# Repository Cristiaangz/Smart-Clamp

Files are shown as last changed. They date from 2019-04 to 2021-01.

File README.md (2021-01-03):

# Smart Clamp Project
This is the GitHub for the Smart Clamp Project under Professor Andras Gyorgy

## 1. Statement of Project Summary
This project aims to develop a low-cost lab equipment add-on that enables remote monitoring of bacterial populations grown in standard lab flasks. The device should be able to accommodate a variety of flasks and bacterial strains, whilst not interfering with the contents’ growth, and utilize IoT capabilities for control and data transmission. Thus, the final prototype will measure cell density, weight, orientation and motion during incubation in temperature controlled shakers, will have inductive wireless charging, WiFi/Bluetooth communication and control capabilities. An onboard microcontroller will be used to direct the device’s functionality. The design layout, material choice, and electronic circuit will be optimized for size, compatibility, power consumption, signal-to-noise ratio, and cost.
## 2. Background and Review of Literature
In the field of microbiology, it is often essential to quantify and monitor cell growth of bacterial populations. Monitoring is done by quantifying cell density over regular time intervals. Quantification is done through either manual counting methods like plating; automated counting methods like flow cytometry; or indirect cell counting like spectrophotometry. All these methodologies have clear drawbacks. Manual and indirect cell counting often requires physical sampling at regular intervals, which requires trained personnel, it is highly time intensive and increases the risk of contamination. Conversely, current automated counting methods require less attention but are either invasive or often prohibitively expensive. Coulter counters require instrumentation to be in contact with the growth medium, making them impractical within an incubator and posing a risk of contamination. Flow cytometry requires highly-specialized and expensive instrumentation, which makes them only accessible to well-funded, high-level research settings where high precision is needed. Thus, a low-cost non-invasive cell-count monitoring system is needed for a large variety of  applications.

This project seeks inspiration from commercially available turbidostats, in their ability to give the user the constant updates on the amount of cells in the apparatus. The instrumentation’s add-on form factor is adopted so that existing experimental protocols require little to no modifications to gain the benefits of the sensory system.  
## 3. Resources 
3D printer, Soldering Tools, Standard Lab Glassware, Basic microbiology equipment. Lab personnel will be available for help. The students and the PI have all the required skillset and tools/equipment for the successful completion of the project.

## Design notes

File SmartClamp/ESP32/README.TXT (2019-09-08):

LAST UPDATED: SEPT 08 2019

This code is meant to work with Esspresif’s ESP32 Dev Board V4 with ESP32-WROOM-32D core. 

PlatformIO is needed to flash the ESP32 with the source code and the required libraries.

PlatformIO is an add-on for Atom or VSCode. It is really helpful as it automatically retrieves and installs libraries for you an allow compile and troubleshoot the same code for different hardware. This can all be defined in the platformio.ini file.

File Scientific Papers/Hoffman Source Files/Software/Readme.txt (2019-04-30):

The turbidostat.ino needs to be flashed onto the Arduino Nano with the Arduino IDE. 
Make sure, the proper driver for the Arduino Nano's chip is installed.

The 'Turbidostat' folder needs to be placed into the current user's home directory. 
(E.g. under Windows typically C:\Users\'UserX')

Start the GUI with the console from the GUI directory with the command 'python turbidostat.py'.

A python distribution containing the used libraries has to be installed.

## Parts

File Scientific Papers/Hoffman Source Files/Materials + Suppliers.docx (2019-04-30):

Part | Supplier URL | Supplier's order number | Price per unit | Amount | total
Electronics, central unit
Photo-coated PCB 200x300 mm | conrad.de | 523695 | 6.86 € | 1 | 6.86 €
MOSFET IRF7103 SO-8 | conrad.de | 162431 | 0.50 € | 2 | 1.00 €
Laser module 1 mW LFD650 | conrad.de | 816476 | 7.50 € | 1 | 7.50 €
bar magnet 5 mm x 20 mm | conrad.de | 505782 | 1.93 € | 2 | 3.86 €
light-to-frequency converter TSL 235 R | conrad.de | 178993 | 3.41 € | 2 | 6.82 €
12V power supply | conrad.de | 512685 | 7.99 € | 1 | 7.99 €
Arduino Nano | reichelt.de | ARDUINO NANO | 24.90 € | 1 | 24.90 €
connector for CPU fan | reichelt.de | PSS 254/3G | 0.05 € | 1 | 0.05 €
female connector, 4 pins | reichelt.de | M 604 | 0.48 € | 2 | 0.96 €
male connector, 4 pins | reichelt.de | B 604 | 0.41 € | 2 | 0.82 €
foil capacitor 4.7 nF | reichelt.de | MKS02-250 4,7N | 0.16 € | 1 | 0.16 €
foil capacitor 100 nF | reichelt.de | MKS-2-5 100N | 0.09 € | 1 | 0.09 €
Hall sensor | reichelt.de | TLE 4905L | 0.67 € | 1 | 0.67 €
12V barrel connector | reichelt.de | HEBW 25 | 0.30 € | 1 | 0.30 €
Female pin header | reichelt.de | BL 1X20G 2,54 | 0.72 € | 2 | 1.44 €
CPU fan 80 mm as stirrer motor | reichelt.de | LÜFTER-8025 12V | 1.45 € | 1 | 1.45 €
long M3 screws, flat-head 50 mm | various suppliers | | 0.30 € | 4 | 1.20 €
sheet metal screws 7 mm | various suppliers | | 0.10 € | 7 | 0.70 €
microscope cover slip as beam splitter | various suppliers | | 0.10 € | 1 | 0.10 €
Tubing system, culture vessel
2x GL 45 lid with tube connectors | carlroth.com | PY86.1 | 50.58 € | 1 | 50.58 €
Luer-tubing connector male | carlroth.com | CT61.1 | 14.16 € | 0.3 | 4.25 €
Luer-tubing connector female | carlroth.com | CT62.1 | 14.16 € | 0.2 | 2.83 €
magnetic stirrer bar, Ø 6 mm x 15 mm | carlroth.com | AKP5.1 | 2.26 € | 1 | 2.26 €
injection cannulas, Ø 2 mm x 100 mm | de.vwr.com | 612-0359 | 50.10 € | 0.25 | 12.53 €
sterile filter 0.2 µm | de.vwr.com | 514-0061 | 33.00 € | 0.02 | 0.66 €
flat bottom test tube 100x25 mm | laborglasshop.de | 100103 | 12.95 € | 0.03 | 0.39 €
pump tubing | gemke-schlauchpumpen.com | Santoprene 4.8x8.0 mm | 10.35 € | 1 | 10.35 €
silicone tubing, inner Ø 5 mm, outer Ø 8 mm | various suppliers | | | | 5.00 €
silicone tubing, inner Ø 1 mm, outer Ø 3 mm | various suppliers | | | | 5.00 €
2 component casting silicone | various suppliers | | | | 2.00 €
Pump unit
12V air pump | pollin.de | 330 036 | 2.50 € | 1 | 2.50 €
peristaltic medium pump | gemke-schlauchpumpen.com | CP82 24V 30 UPM | 45.00 € | 1 | 45.00 €
pump housing | conrad.de | 526033 | 8.08 € | 1 | 8.08 €
total | | | | | 218.29 €

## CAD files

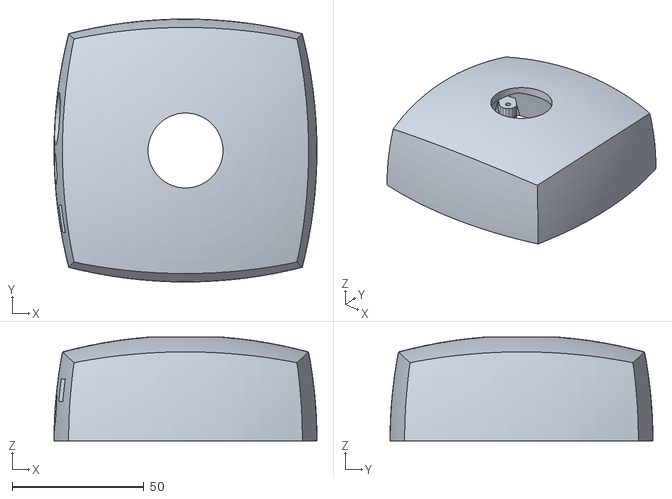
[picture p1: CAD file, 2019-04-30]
Scientific Papers/Hoffman Source Files/journal/upper housing.stl
100.0 x 100.0 x 39.4

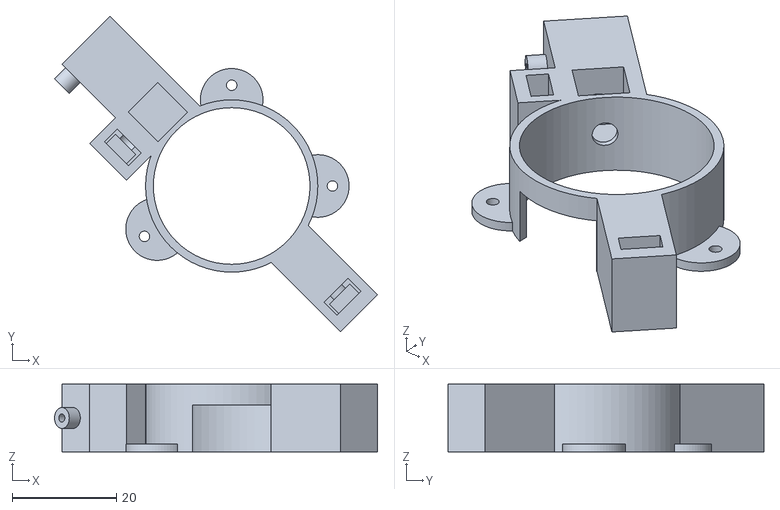
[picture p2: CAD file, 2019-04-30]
Scientific Papers/Hoffman Source Files/journal/optics holder.stl
61.9 x 60.5 x 13.0

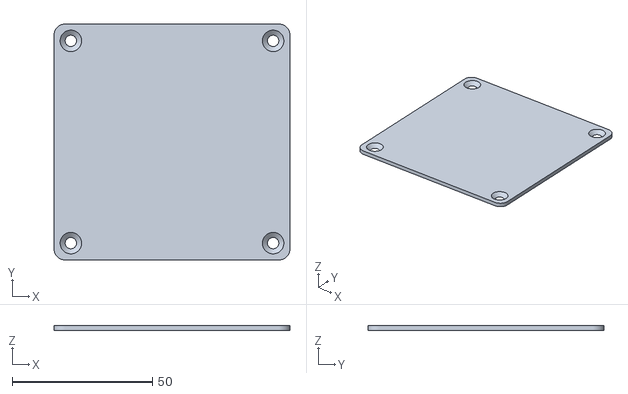
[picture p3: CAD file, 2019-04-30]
Scientific Papers/Hoffman Source Files/journal/bottom cover.stl
84.0 x 84.0 x 1.80

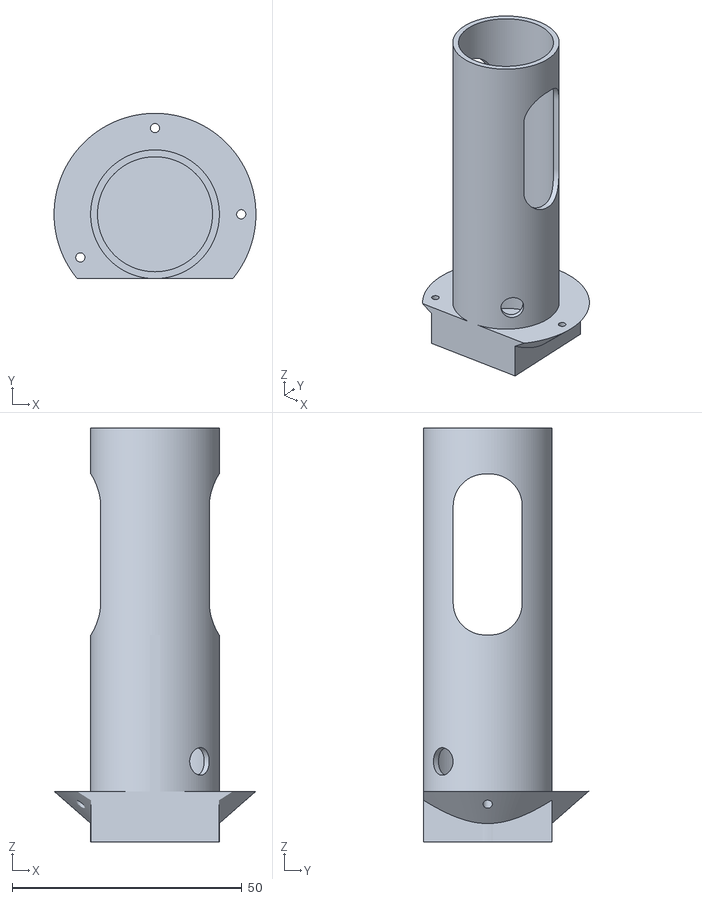
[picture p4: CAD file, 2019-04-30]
Scientific Papers/Hoffman Source Files/journal/tube holder.stl
43.9 x 36.0 x 90.0

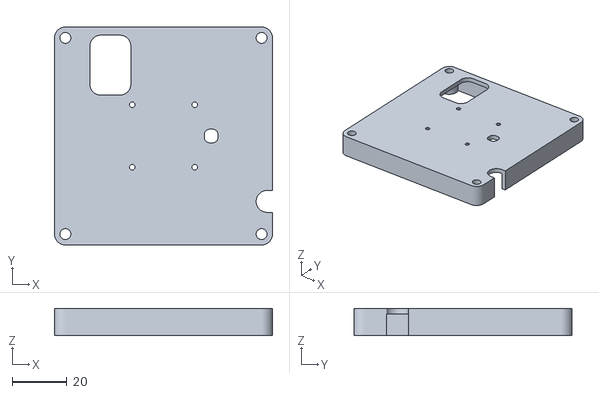
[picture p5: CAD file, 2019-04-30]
Scientific Papers/Hoffman Source Files/journal/base plate.stl
80.0 x 80.0 x 10.0

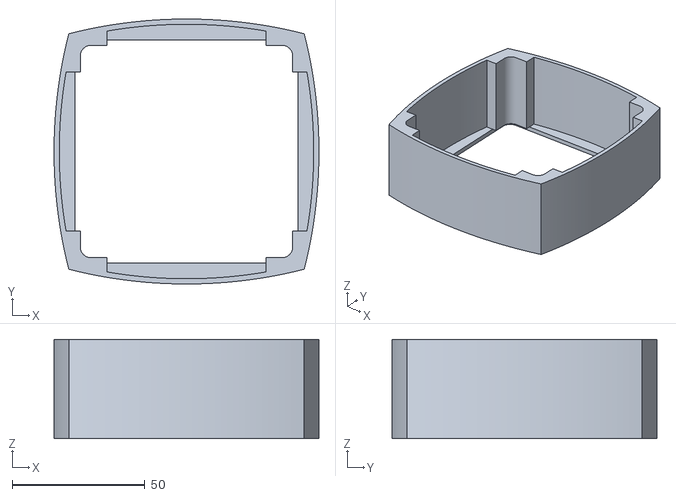
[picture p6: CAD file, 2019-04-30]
Scientific Papers/Hoffman Source Files/journal/lower housing.stl
100.0 x 100.0 x 37.5

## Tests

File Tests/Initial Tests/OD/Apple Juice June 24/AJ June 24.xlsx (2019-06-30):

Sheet: All
Time [s] | 0%1 | 0%2 | 10%1 | 10%2 | 20%1 | 20%2 | 30%1 | 30%2 | 40%1 | 40%2 | 50%1 | 50%2 | 60%1 | 60%2
0 | 0 | 0 | 0 | 0 | 0 | 0 | 0 | 0 | 0 | 0 | 0 | 0 | 0 | 0
1 | 0 | 0 | 0 | 0 | 0 | 0 | 0 | 0 | 0 | 0 | 0 | 0 | 0 | 0
2 | 0 | 0 | 0 | 0 | 0 | 0 | 0 | 0 | 0 | 0 | 0 | 0 | 0 | 0
3 | 0 | 0 | 0 | 0 | 0 | 0 | 0 | 0 | 0 | 0 | 0 | 0 | 0 | 0
4 | 0 | 0 | 0 | 0 | 0 | 0 | 0 | 0 | 0 | 0 | 0 | 0 | 0 | 0
5 | 0 | 0 | 0 | 0 | 0 | 0 | 0 | 0 | 0 | 0 | 0 | 0 | 0 | 0
6 | 0 | 0 | 0 | 0 | 0 | 0 | 0 | 0 | 0 | 0 | 0 | 0 | 0 | 0
7 | 0 | 0 | 0 | 0 | 0 | 0 | 0 | 0 | 0 | 0 | 0 | 0 | 0 | 0
8 | 0 | 0 | 0 | 0 | 0 | 0 | 0 | 0 | 0 | 0 | 0 | 0 | 0 | 0
9 | 0 | 0 | 0 | 0 | 0 | 0 | 0 | 0 | 0 | 0 | 0 | 0 | 0 | 0
10 | 0 | 0 | 0 | 0 | 0 | 0 | 0 | 0 | 0 | 0 | 0 | 0 | 0 | 0
11 | 0 | 0 | 0 | 0 | 0 | 0 | 0 | 0 | 0 | 0 | 0 | 0 | 0 | 0
12 | 0 | 0 | 0 | 0 | 0 | 0 | 0 | 0 | 0 | 0 | 0 | 0 | 0 | 0
13 | 0 | 0 | 0 | 0 | 0 | 0 | 0 | 0 | 0 | 0 | 0 | 0 | 0 | 0
14 | 0 | 0 | 0 | 0 | 0 | 0 | 0 | 0 | 0 | 0 | 0 | 0 | 0 | 0
15 | 0 | 0 | 0 | 0 | 0 | 0 | 0 | 0 | 0 | 0 | 0 | 0 | 0 | 0
16 | 0 | 0 | 0 | 0 | 0 | 0 | 0 | 0 | 0 | 0 | 0 | 0 | 0 | 0
17 | 0 | 0 | 0 | 0 | 0 | 0 | 0 | 0 | 0 | 0 | 0 | 0 | 0 | 0
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

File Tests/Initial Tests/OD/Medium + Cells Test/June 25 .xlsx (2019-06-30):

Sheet: Raw Data
Time [s] | Sat1 | Sat2 | Sat3 | 1/2 1 | 1/2 2 | 1/2 3 | 1/4 1 | 1/4 2 | 1/4 3 | 1/8 1 | 1/8 2 | 1/8 3 | 1/16 1 | 1/16 2 | 1/16 3 | 1/32 1 | 1/32 2 | 1/32 3 | 1/64 1 | 1/64 2 | 1/64 3 | 1/128 1 | 1/128 2 | 1/128 3 | LB1 | LB2 | LB3
0 | 0 | 0 | 0 | 0 | 0 | 0 | 0 | 0 | 0 | 0 | 0 | 0 | 0 | 0 | 0 | 0 | 0 | 0 | 0 | 0 | 0 | 0 | 0 | 0 | 0 | 0 | 0
1 | 0 | 0 | 0 | 0 | 0 | 0 | 0 | 0 | 0 | 0 | 0 | 0 | 0 | 0 | 0 | 0 | 0 | 0 | 0 | 0 | 0 | 0 | 0 | 0 | 0 | 0 | 0
2 | 0 | 0 | 0 | 0 | 0 | 0 | 0 | 0 | 0 | 0 | 0 | 0 | 0 | 0 | 0 | 0 | 0 | 0 | 0 | 0 | 0 | 0 | 0 | 0 | 0 | 0 | 0
3 | 0 | 0 | 0 | 0 | 0 | 0 | 0 | 0 | 0 | 0 | 0 | 0 | 0 | 0 | 0 | 0 | 0 | 0 | 0 | 0 | 0 | 0 | 0 | 0 | 0 | 0 | 0
4 | 0 | 0 | 0 | 0 | 0 | 0 | 0 | 0 | 0 | 0 | 0 | 0 | 0 | 0 | 0 | 0 | 0 | 0 | 0 | 0 | 0 | 0 | 0 | 0 | 0 | 0 | 0
5 | 0 | 0 | 0 | 0 | 0 | 0 | 0 | 0 | 0 | 0 | 0 | 0 | 0 | 0 | 0 | 0 | 0 | 0 | 0 | 0 | 0 | 0 | 0 | 0 | 0 | 0 | 0
6 | 0 | 0 | 0 | 0 | 0 | 0 | 0 | 0 | 0 | 0 | 0 | 0 | 0 | 0 | 0 | 0 | 0 | 0 | 0 | 0 | 0 | 0 | 0 | 0 | 0 | 0 | 0
7 | 0 | 0 | 0 | 0 | 0 | 0 | 0 | 0 | 0 | 0 | 0 | 0 | 0 | 0 | 0 | 0 | 0 | 0 | 0 | 0 | 0 | 0 | 0 | 0 | 0 | 0 | 0
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

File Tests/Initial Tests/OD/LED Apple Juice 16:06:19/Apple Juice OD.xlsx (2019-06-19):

Time | 100% Uncap | 90% Uncap | 80% Uncap | 70% Uncap | 60% Uncap | 50% Uncap | 40% Uncap | 30% Uncap | 20% Uncap | 10% Uncap | 0% Uncap | No Flask
1 | 2626 | 2636 | 2736 | 2773 | 2927 | 3773 | 4422 | 4881 | 5578 | 5836 | 8417 | 2473
2 | 61424 | 64431 | 59963 | 58893 | 60240 | 60019 | 65337 | 63732 | 65390 | 64059 | 68981 | 70966
3 | 61529 | 64438 | 59955 | 58682 | 60228 | 59970 | 65142 | 63764 | 65534 | 64083 | 68697 | 71170
4 | 61650 | 64211 | 59984 | 58808 | 60212 | 59888 | 64940 | 63856 | 65420 | 64056 | 68624 | 71158
5 | 61585 | 64356 | 59935 | 58985 | 60298 | 59989 | 64683 | 63927 | 65607 | 64132 | 68583 | 71144
6 | 61422 | 64334 | 59911 | 59005 | 60046 | 59980 | 64574 | 64091 | 65473 | 64171 | 68606 | 71132
7 | 61410 | 64251 | 59942 | 59001 | 59920 | 60004 | 64439 | 64278 | 65083 | 64203 | 68643 | 71116
8 | 61451 | 64153 | 59873 | 58997 | 60010 | 59999 | 64350 | 64304 | 64596 | 64183 | 68672 | 66573
9 | 61510 | 64058 | 59847 | 56631 | 59809 | 59956 | 64249 | 64330 | 65384 | 64213 | 68611 | 71120
10 | 61531 | 64007 | 59860 | 58996 | 59605 | 59956 | 64062 | 64218 | 65674 | 64303 | 68622 | 71119
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

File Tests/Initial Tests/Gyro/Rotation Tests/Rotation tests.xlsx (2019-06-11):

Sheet: Static 10 Hz
Time [s] | AcX | AcY | AcZ | Gtemp | GyX | GyY | GyZ
0.1 | -404 | -240 | -16708 | 22.93 | -517 | -212 | 12 | RPM | 0
0.2 | -368 | -192 | -16600 | 22.93 | -495 | -241 | 11
0.3 | -388 | -180 | -16724 | 22.88 | -485 | -239 | 23
0.4 | -364 | -216 | -16772 | 22.98 | -481 | -215 | 13
0.5 | -368 | -84 | -16584 | 22.93 | -518 | -238 | 10
0.6 | -440 | -132 | -16584 | 22.93 | -473 | -239 | 9
0.7 | -332 | -156 | -16692 | 22.84 | -485 | -201 | 14
0.8 | -376 | -196 | -16576 | 22.98 | -481 | -238 | 4
0.9 | -348 | -112 | -16664 | 22.88 | -503 | -194 | 14
1 | -360 | -128 | -16696 | 22.88 | -486 | -233 | 18
1.1 | -328 | -184 | -16676 | 22.98 | -479 | -228 | 8
1.2 | -368 | -100 | -16620 | 22.88 | -521 | -206 | 8
1.3 | -344 | -200 | -16676 | 22.84 | -476 | -235 | 1
1.4 | -404 | -204 | -16740 | 22.93 | -486 | -228 | 32
1.5 | -356 | -160 | -16632 | 22.84 | -501 | -216 | 12
1.6 | -268 | -176 | -16652 | 22.98 | -490 | -216 | -1
1.7 | -432 | -216 | -16860 | 22.84 | -487 | -219 | 11
1.8 | -492 | -220 | -16744 | 22.93 | -508 | -219 | 15
1.9 | -312 | -140 | -16528 | 22.84 | -483 | -225 | 10
2 | -336 | -180 | -16620 | 22.98 | -477 | -202 | 2
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

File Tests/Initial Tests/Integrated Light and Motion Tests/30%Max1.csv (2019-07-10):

Time [s] | Intensity A | Laser On | AcX | AcY | AcZ | GyX | GyY | GyZ | MPU Temp [C]
0.0 | 16.666666666666700 | TRUE | 0 | 0 | 0 | 0 | 0 | 0 | 25.4
0.10 | 550.0 | TRUE | 0 | 0 | 0 | 0 | 0 | 0 | 25.4
0.20 | 2150.0 | TRUE | 0 | 0 | 0 | 0 | 0 | 0 | 25.4
0.30 | 2150.0 | TRUE | 0 | 0 | 0 | 0 | 0 | 0 | 25.4
0.40 | 2166.6666666666700 | TRUE | 0 | 0 | 0 | 0 | 0 | 0 | 25.4
0.50 | 2166.6666666666700 | TRUE | 0 | 0 | 0 | 0 | 0 | 0 | 25.4
0.60 | 2150.0 | TRUE | 0 | 0 | 0 | 0 | 0 | 0 | 25.4
0.70 | 2166.6666666666700 | TRUE | 0 | 0 | 0 | 0 | 0 | 0 | 25.4
0.80 | 2150.0 | TRUE | 0 | 0 | 0 | 0 | 0 | 0 | 25.4
0.90 | 2166.6666666666700 | TRUE | 0 | 0 | 0 | 0 | 0 | 0 | 25.4
0.100 | 2166.6666666666700 | TRUE | 0 | 0 | 0 | 0 | 0 | 0 | 25.4
0.110 | 2166.6666666666700 | TRUE | 0 | 0 | 0 | 0 | 0 | 0 | 25.4
0.120 | 2150.0 | TRUE | 0 | 0 | 0 | 0 | 0 | 0 | 25.4
0.130 | 2166.6666666666700 | TRUE | 0 | 0 | 0 | 0 | 0 | 0 | 25.4
0.140 | 2166.6666666666700 | TRUE | 0 | 0 | 0 | 0 | 0 | 0 | 25.4
0.150 | 2150.0 | TRUE | 0 | 0 | 0 | 0 | 0 | 0 | 25.4
0.160 | 2166.6666666666700 | TRUE | 0 | 0 | 0 | 0 | 0 | 0 | 25.4
0.170 | 2166.6666666666700 | TRUE | 0 | 0 | 0 | 0 | 0 | 0 | 25.4
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

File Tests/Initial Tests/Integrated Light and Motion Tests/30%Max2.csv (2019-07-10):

Time [s] | Intensity A | Laser On | AcX | AcY | AcZ | GyX | GyY | GyZ | MPU Temp [C]
0.0 | 16.666666666666700 | TRUE | 0 | 0 | 0 | 0 | 0 | 0 | 25.49411764705880
0.10 | 633.3333333333330 | TRUE | 0 | 0 | 0 | 0 | 0 | 0 | 25.49411764705880
0.20 | 2183.3333333333300 | TRUE | 0 | 0 | 0 | 0 | 0 | 0 | 25.49411764705880
0.30 | 2200.0 | TRUE | 0 | 0 | 0 | 0 | 0 | 0 | 25.49411764705880
0.40 | 2166.6666666666700 | TRUE | 0 | 0 | 0 | 0 | 0 | 0 | 25.49411764705880
0.50 | 2183.3333333333300 | TRUE | 0 | 0 | 0 | 0 | 0 | 0 | 25.49411764705880
0.60 | 2200.0 | TRUE | 0 | 0 | 0 | 0 | 0 | 0 | 25.49411764705880
0.70 | 2183.3333333333300 | TRUE | 0 | 0 | 0 | 0 | 0 | 0 | 25.49411764705880
0.80 | 2166.6666666666700 | TRUE | 0 | 0 | 0 | 0 | 0 | 0 | 25.49411764705880
0.90 | 2183.3333333333300 | TRUE | 0 | 0 | 0 | 0 | 0 | 0 | 25.49411764705880
0.100 | 2183.3333333333300 | TRUE | 0 | 0 | 0 | 0 | 0 | 0 | 25.49411764705880
0.110 | 2183.3333333333300 | TRUE | 0 | 0 | 0 | 0 | 0 | 0 | 25.49411764705880
0.120 | 2183.3333333333300 | TRUE | 0 | 0 | 0 | 0 | 0 | 0 | 25.49411764705880
0.130 | 2183.3333333333300 | TRUE | 0 | 0 | 0 | 0 | 0 | 0 | 25.49411764705880
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

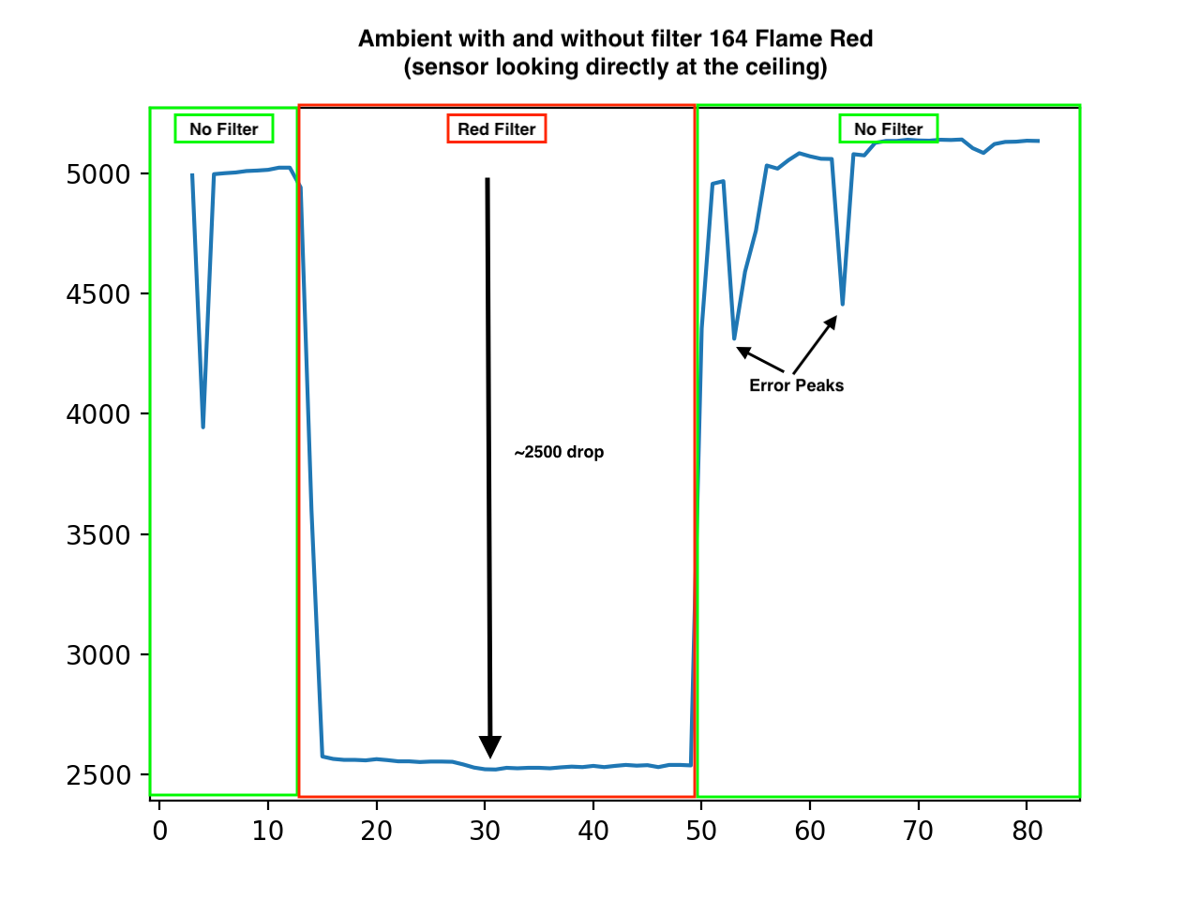
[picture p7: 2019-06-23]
Tests/Initial Tests/OD/Light Detection June 23 2019/Filtered ambient light.png

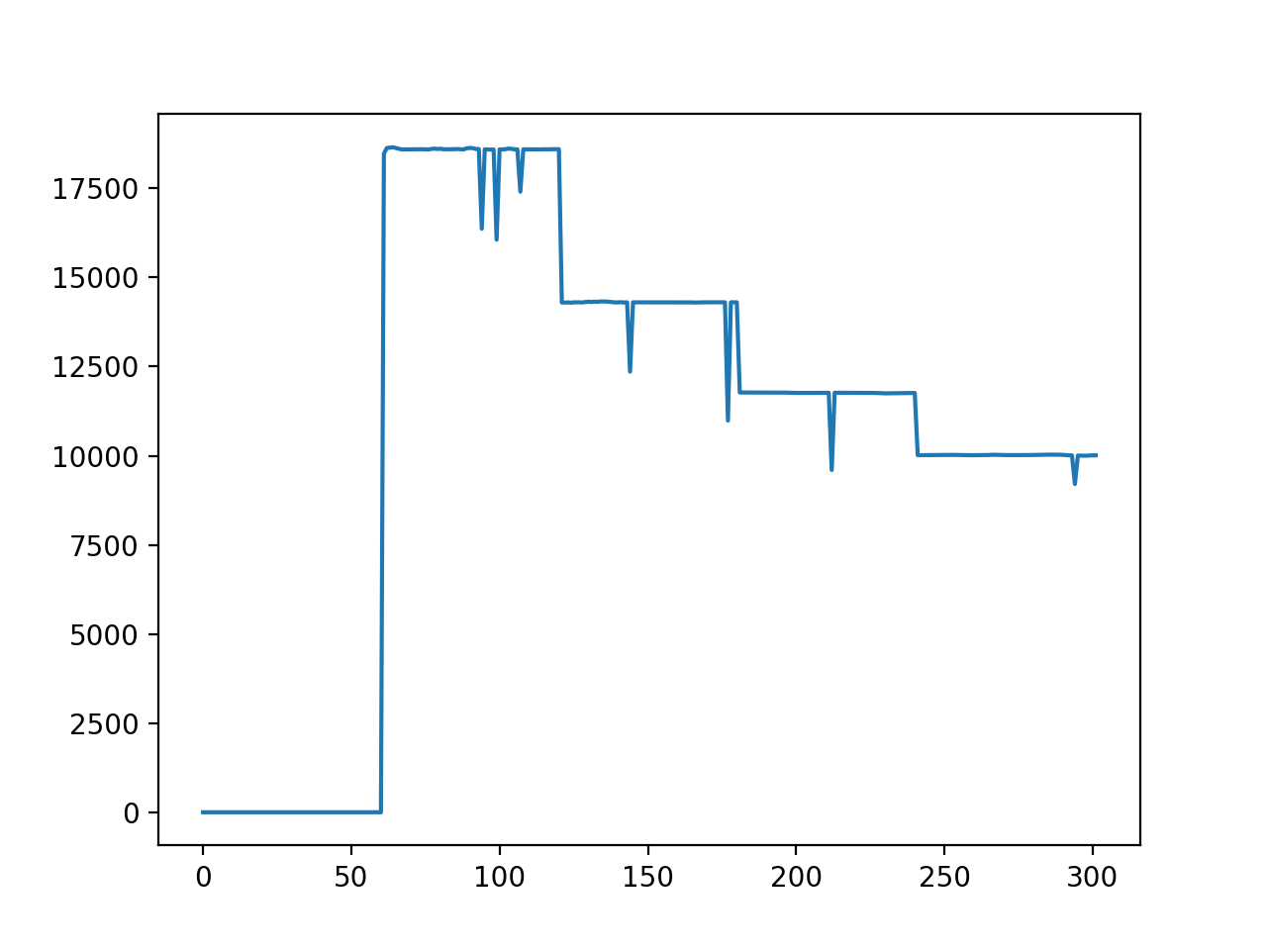
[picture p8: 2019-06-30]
Tests/Initial Tests/OD/Apple Juice June 24/40%AJ2.png

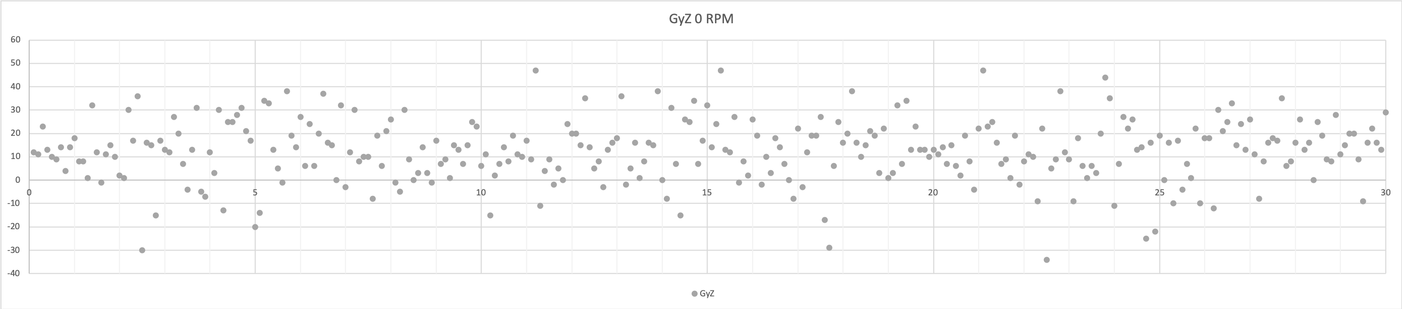
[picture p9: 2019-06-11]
Tests/Initial Tests/Gyro/Rotation Tests/10Hz/Graphs/Static.png/Static.png-6.png

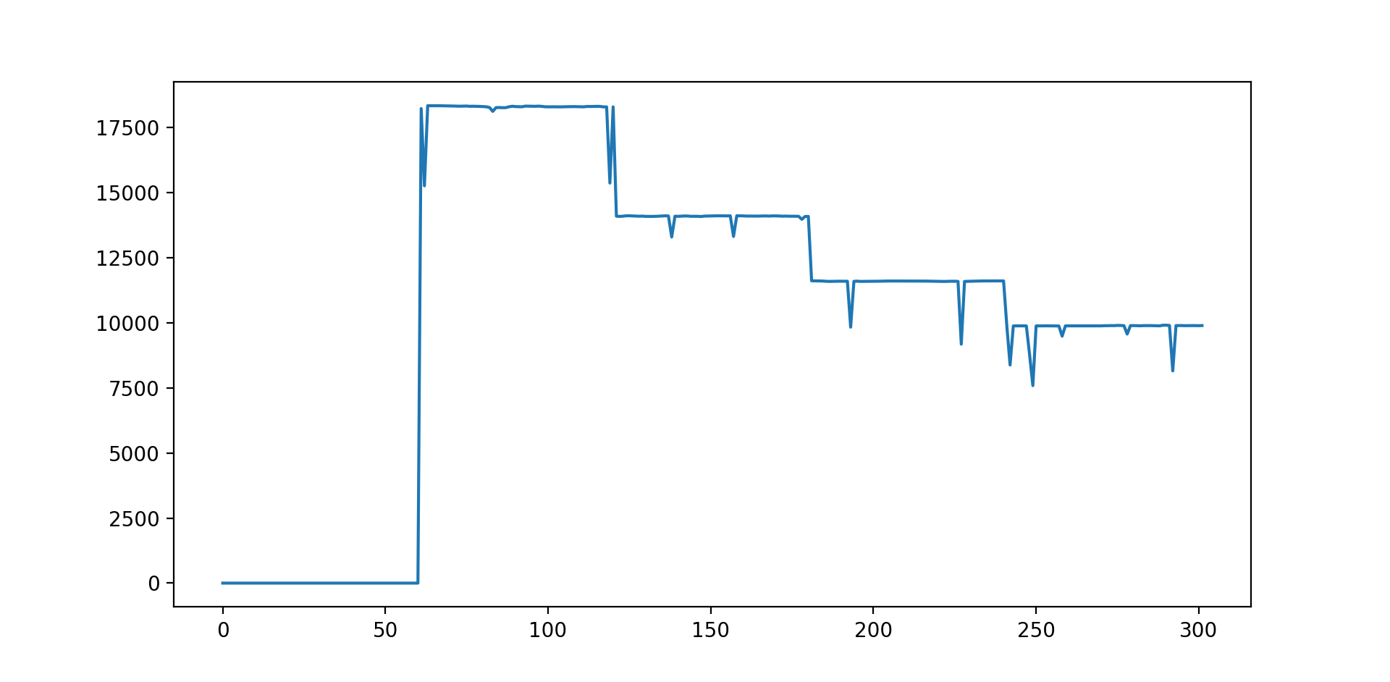
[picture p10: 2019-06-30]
Tests/Initial Tests/OD/Apple Juice June 24/60%AJ1.png

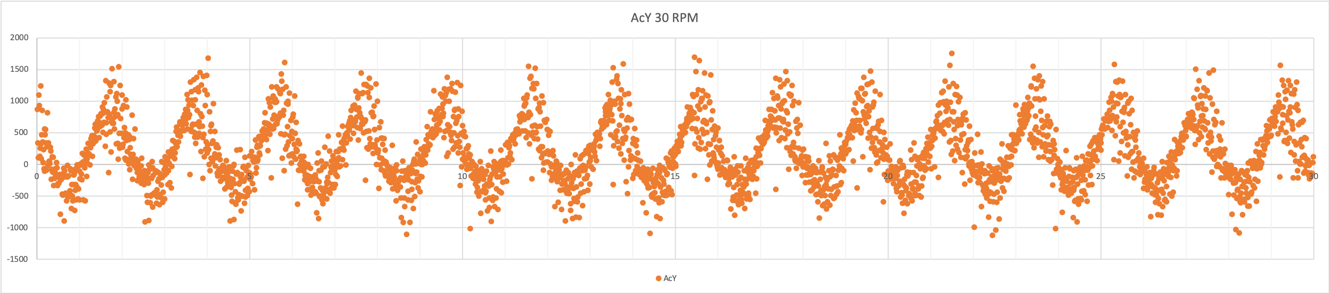
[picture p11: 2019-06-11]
Tests/Initial Tests/Gyro/Rotation Tests/100 Hz/Graphs/30 Hz 11:06:19.png/30 Hz 11:06:19.png-2.png

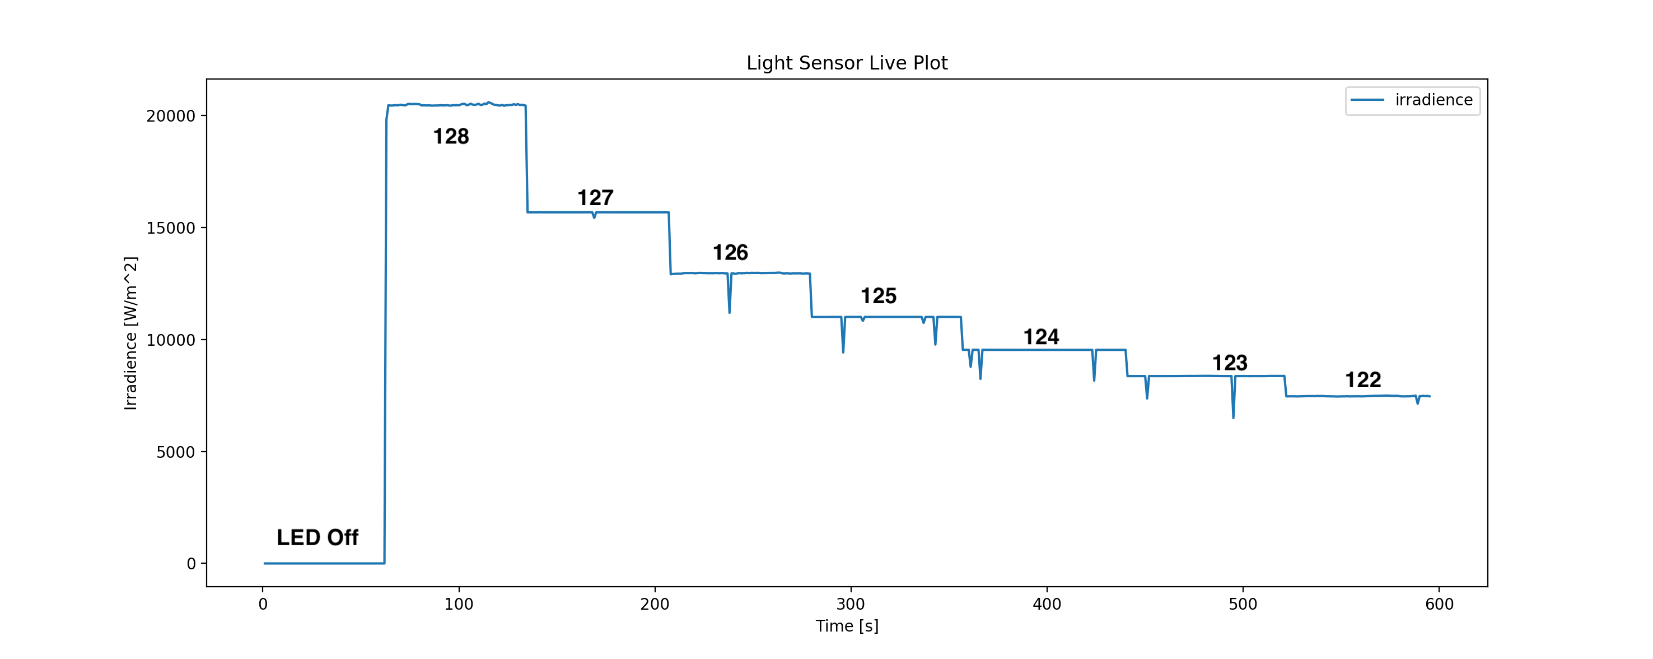
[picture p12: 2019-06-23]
Tests/Initial Tests/OD/Light Detection June 23 2019/LED_no_filter.png

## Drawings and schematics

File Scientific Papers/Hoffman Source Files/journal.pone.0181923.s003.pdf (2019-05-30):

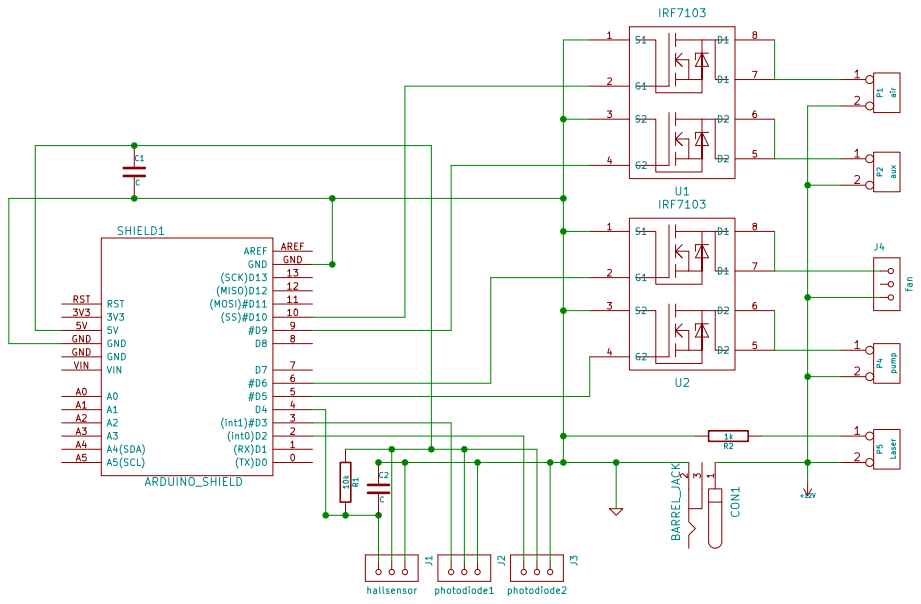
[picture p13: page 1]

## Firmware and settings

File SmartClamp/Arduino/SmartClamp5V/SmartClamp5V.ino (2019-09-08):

/*
 *    FILE: SmartClamp.ino
 *  AUTHOR: Cristian Garcia (Based on turbidostat.ino by Christian Wohltat, Stefan Hoffman)
 *    DATE: 2019 19 01
 */

//////////////////////////////////////////////////////////////////////////////////
//
//  Definitions and Declarations
//
//////////////////////////////


#define SMARTCLAMP_VERSION  "0.13"
#include <PinChangeInt.h>                                              // DEPRECATED: Should consider chanaging to EnableInterrupt.h Library when given the time
#include <Wire.h>                                                      //Enables I2C Comms
#include <SPI.h>                                                       //Enables SPI Comms
#include <SFE_MicroOLED.h>                                             // Include the SFE_MicroOLED library
//#include <MPU6050_tockn>                                             //MPU6050 reference library




//Serial Comms
#define SERIAL_BUFFER_LEN 128                                          // Defines Arduino buffer as 128 bytes instead of 64                                                  // Interval of sent data
char serialBuffer[SERIAL_BUFFER_LEN];
unsigned short bufferEnd = 0;
unsigned short bufferPos = 0;




// Light Detection
#define SENSOR_A_PIN  2
#define LIGHT_PIN     4
#define POT_PIN       5
#define POT_ADDR      0x00

bool lightOn = false;
bool sensor_Enable = true;
volatile unsigned long cnta = 0;
unsigned long oldcnta = 0;
float Ia = 0;                                                          // current intensity of sensor A in uW/m2
byte light_int = 128;                                                  //Changes potentiometer resistance from 10kΩ to 0Ω [0-128]
byte light_sampling = 1;



// OLED Display
#define CS_OLED   10
#define PIN_RESET 9                                                    // Connect RST to pin 9
#define PIN_DC    8                                                    // Connect DC to pin 8
#define DC_JUMPER 0                                                    // Set to either 0 (SPI, default) or 1 (I2C) based on jumper, matching the value of the DC Jumper
MicroOLED oled(PIN_RESET, PIN_DC, CS_OLED);                             //SPI declaration

byte secs, mins, hours = 0;
bool Display = false;




// Gyroscope
#define MPU_ADDR 0x068                                                 // I2C address of the MPU-6050
byte mpu_sampling = 1;

long gyro_x_cal, gyro_y_cal, gyro_z_cal;
short gyro_x, gyro_y, gyro_z;
short acc_x, acc_y, acc_z;
short temp_mpu;
bool mpu_Enable = false;




//  Time Keeping
volatile unsigned long msecs = 0;
volatile unsigned long oldmsecs = 0;
volatile unsigned long ledMsecs = 0;
volatile unsigned long mpuMsecs = 0;
unsigned long refSec = 0;
unsigned short ref_led_msecs = 0;
unsigned short ref_mpu_msecs = 0;
byte light_Cycle = -1;





///////////////////////////////////////////////////////////////////
//
// SETUP
//


void setup() {
  //Initialization
  Wire.begin();                                                        //Start I2C as master
  Serial.begin(115200);                                                 //Start Serial Channel
  Serial.println("START$");                                            //Let PC know program started  
  Serial.println((String)"SMARTCLAMP version: " + SMARTCLAMP_VERSION + "$");
  oledSetup();

  // Pin Declarations
  pinMode(SENSOR_A_PIN, INPUT);                                        //Set Light Sensor as Input
  digitalWrite(SENSOR_A_PIN, HIGH);

  pinMode(LIGHT_PIN, OUTPUT);                                          //Set Light Pin as Output
  digitalWrite(LIGHT_PIN, LOW);                                        //Start Light Source as Off

  pinMode(POT_PIN, OUTPUT);                                            // Set Potentiometer's CS pin for SPI as Output


  // MPU Setup
  registers_Error();
  setup_mpu_6050_registers();                                          //Setup the registers of the MPU-6050 (500dfs / +/-8g) and start the gyro
  calibrate_Gyro();

  SPI.begin();
  write_potentiometer((byte)105);
  attachInterrupt(0, isr1, RISING);                                    //Interrupt function isr1 triggered by rising edge at PIN D2
  Timer2init();
  Serial.println("READY$");
}


///////////////////////////////////////////////////////////////////
//
// Main Loop
//


void loop() {

  if (msecs - oldmsecs >= 1000){

      oldmsecs = msecs;
      refSec++;
      ref_led_msecs = 0;
      ref_mpu_msecs = 0;
      Serial.print("\tt=");
      Serial.print((int)refSec);
      Serial.println("$");
  }
  
  light_Cycle = display_Switch(light_Cycle);
  check_MPU();
  check_Light();
}

//////////////////////////////////////////////////////////////////////////////////
//
// Functions
//
//////////////////////////////


                                  // SERIAL FUNCTIONS
                                  

void read_SERIAL(){                                                  // Subroutine for reading Serial Buffer
  if (Serial.available() > 0) {
    // get incoming byte:
    serialBuffer[bufferEnd] = Serial.read();
    Serial.print(serialBuffer[bufferEnd]);

    // min message length? -> process commands
    if( serialBuffer[bufferEnd] == 10 ) {
      processSerialBuffer();

      // go to message end
      bufferPos = bufferEnd+1;
    }

    if( bufferEnd < SERIAL_BUFFER_LEN - 1 )
      bufferEnd++;
    else
      bufferEnd = 0;
  }
}

void processSerialBuffer(){                                          // Subroutine for processing commands in Serial Buffer
  if( toupper(serialBuffer[bufferPos]) == 'L'){
    if( toupper(serialBuffer[bufferPos+1]) == 'O'){
      if( toupper(serialBuffer[bufferPos+2]) == 'N'){
        // LON - Laser ON
        lightOn = true;
        Serial.print("Light On: ");
        Serial.print(lightOn);
        Serial.println("$");
        digitalWrite(LIGHT_PIN, HIGH);
      }
      else if( toupper(serialBuffer[bufferPos+2]) == 'F'){
        // LOF - Laser OF
        lightOn = false;
        Serial.print("Light On: ");
        Serial.print(lightOn);
        Serial.println("$");
        digitalWrite(LIGHT_PIN, LOW);
      }
    }
  }

  if( toupper(serialBuffer[bufferPos]) == 'D'){
    if( toupper(serialBuffer[bufferPos+1]) == 'O'){
      if( toupper(serialBuffer[bufferPos+2]) == 'N'){
        // DON - Display ON
        Display = true;
        Serial.println("Display On$");
      }
      else if( toupper(serialBuffer[bufferPos+2]) == 'F'){
        // DOF - Display OFF
        Display = false;
        Serial.println("Display Off$");
        oled.clear(PAGE);
        oled.display();  
      }
    }
  }
  
  if( toupper(serialBuffer[bufferPos]) == 'M'){
    if( toupper(serialBuffer[bufferPos+1]) == 'O'){
      if( toupper(serialBuffer[bufferPos+2]) == 'N'){
        // DON - Display ON
        mpu_Enable = true;
        Serial.println("MPU Enabled$");
      }
      else if( toupper(serialBuffer[bufferPos+2]) == 'F'){
        // DOF - Display OFF
        mpu_Enable = false;
        Serial.println("MPU Disabled$");
      }
    }
  }
  
  if( toupper(serialBuffer[bufferPos]) == 'S'){
    if( toupper(serialBuffer[bufferPos+1]) == 'L'){
      if( toupper(serialBuffer[bufferPos+2]) == 'I'){
        // SLI - Set Light Intensity
        bufferPos += 3;
        light_int = getSerialLongArgument();
        write_potentiometer(light_int);
      }
      if( toupper(serialBuffer[bufferPos+2]) == 'S'){
        // SMS - Set MPU Sampling
        bufferPos += 3;
        light_sampling = getSerialIntArgument();
        Serial.print("Light Sampling set to: ");
        Serial.print(light_sampling);
        Serial.println("$");
      }
    }
    if( toupper(serialBuffer[bufferPos+1]) == 'M'){
      if( toupper(serialBuffer[bufferPos+2]) == 'S'){
        // SMS - Set MPU Sampling
        bufferPos += 3;
        mpu_sampling = getSerialIntArgument();
        Serial.print("MPU Sampling set to: ");
        Serial.print(mpu_sampling);
        Serial.println("$");
        }
    }
    if( toupper(serialBuffer[bufferPos+1]) == 'O'){
        if( toupper(serialBuffer[bufferPos+2]) == 'N'){
          // DON - Sensor ON
          sensor_Enable = true;
          Serial.println("Sensor Enabled$");
        }
      else if( toupper(serialBuffer[bufferPos+2]) == 'F'){
        // DOF - Sensor OFF
        sensor_Enable = false;
        Serial.println("Sensor Disabled$");
      }
    }
  }
}

void write_SERIAL_LED(){                                                 //Subroutine for writing toSerial
  Serial.print("\tms=");
  Serial.print(ref_led_msecs);
  Serial.print("\tI=");
  Serial.print((float)Ia);
  Serial.print("\tl=");
  Serial.print(lightOn);
  Serial.print("\ttm=");
  Serial.print((int)temp_mpu);
//  Serial.print("\tta=");
//  Serial.print(getArduinoTemp(),2);
  Serial.println("$");
}


void write_SERIAL_MPU(){                                                 //Subroutine for writing toSerial
  Serial.print("\tms=");
//  Serial.print("\t");
  Serial.print(ref_mpu_msecs);
  Serial.print("\tgx=");
//  Serial.print("\t");
  Serial.print((short)gyro_x);
  Serial.print("\tgy=");
//  Serial.print("\t");
  Serial.print((short)gyro_y);
  Serial.print("\tgz=");
//  Serial.print("\t");
  Serial.print((short)gyro_z);
  Serial.print("\tax=");
//  Serial.print("\t");
  Serial.print((short)acc_x);
  Serial.print("\tay=");
//  Serial.print("\t");
  Serial.print((short)acc_y);
  Serial.print("\taz=");
//  Serial.print("\t");
  Serial.print((short)acc_z);
  Serial.println("$");
}


void write_SERIAL_CAL(){                                                    //Subroutine for writing toSerial
  Serial.print("\tgxc=");
//  Serial.print("\t");
  Serial.print((short)gyro_x_cal);
  Serial.print("\tgyc=");
//  Serial.print("\t");
  Serial.print((short)gyro_y_cal);
  Serial.print("\tgzc=");
//  Serial.print("\t");
  Serial.print((short)gyro_z_cal);
  Serial.println("$");
}

unsigned int getSerialIntArgument(){
  return atoi(serialBuffer+(bufferPos+1) );
}

unsigned long getSerialLongArgument(){
  return atol(serialBuffer+(bufferPos+1) );
}

float getSerialFloatArgument(){
  return atof(serialBuffer+(bufferPos+1) );
}






                                  // LIGHT DETECTOR FUNCTIONS

void process_light_sensor(){
  
  unsigned short na = cnta - oldcnta;
  oldcnta = cnta;
  Ia = ((float)na*light_sampling);
  
}

void write_potentiometer(int value)
{
  Serial.print("SLI ");
  Serial.print(value);
  Serial.println("$");
  digitalWrite(POT_PIN, LOW);
  SPI.transfer(POT_ADDR);
  SPI.transfer(value);
  digitalWrite(POT_PIN, HIGH);
}

void check_Light(){
  if ((msecs - ledMsecs >= (1000/light_sampling)) and sensor_Enable){
//      Serial.println((String)"#" + msecs);                          //DEBUG: Used to check process' period
      ledMsecs = msecs;
      light_Cycle = 1;
      process_light_sensor();
//      Serial.println((String)"#" + msecs);                          //DEBUG: Used to check process' period
  }  
}

byte display_Switch(byte light_Cycle){
  
  switch(light_Cycle){
    
    case 1:
      light_Cycle++;
      write_SERIAL_LED();
      ref_led_msecs += (1000/light_sampling);
      return(light_Cycle);

    case 2:
      processTime();
      if (Display){light_Cycle++;}
      else{light_Cycle = 0;}
      return(light_Cycle);

    case 3:
      oledProcess1();
      light_Cycle++;
      return(light_Cycle);

    case 4:
      oledProcess2();
      light_Cycle++;
      return(light_Cycle);

    case 5:
      oledProcess3();
      light_Cycle++;
      return(light_Cycle);

    case 6:
      oledProcess4();
      light_Cycle++;
      return(light_Cycle);

    case 7:
      oledProcess5();
      light_Cycle++;
      return(light_Cycle);

    default:
      read_SERIAL();
      return(light_Cycle);
  }  
}



                                  // MPU 6050 FUNCTIONS


void setup_mpu_6050_registers(){
  
  //Activate the MPU-6050
  Wire.beginTransmission(0x68);                                        //Start communicating with the MPU-6050
  Wire.write(0x6B);                                                    //Send the requested starting register
  Wire.write(0x00);                                                    //Set the requested starting register
  Wire.endTransmission();                                              //End the transmission
  //Configure the accelerometer (+/-8g)
  Wire.beginTransmission(0x68);                                        //Start communicating with the MPU-6050
  Wire.write(0x1C);                                                    //Send the requested starting register
  Wire.write(0x10);                                                    //Set the requested starting register
  Wire.endTransmission();                                              //End the transmission
  //Configure the gyro (500dps full scale)
  Wire.beginTransmission(0x68);                                        //Start communicating with the MPU-6050
  Wire.write(0x1B);                                                    //Send the requested starting register
  Wire.write(0x08);                                                    //Set the requested starting register
  Wire.endTransmission();                                              //End the transmission
}




void calibrate_Gyro(){
  oled.clear(PAGE);                                                    // Clear the buffer.
  oled.setCursor(0, 0);                                                // Set cursor to top-left
  oled.setFontType(0);                                                 // Smallest font
  oled.print("GYRO CAL");
  oled.setCursor(0, 16);                                               // Set cursor to top-middle-left
  oled.print("DONT");
  oled.setCursor(0, 32);
  oled.print("MOVE");
  oled.display();
  Serial.println("CALIBRATING$"); 
  
  for (int cal_int = 0; cal_int < 2000 ; cal_int ++){                  //Run this code 2000 times
    read_mpu_6050_data();                                              //Read the raw acc and gyro data from the MPU-6050
    gyro_x_cal += gyro_x;                                              //Add the gyro x-axis offset to the gyro_x_cal variable
    gyro_y_cal += gyro_y;                                              //Add the gyro y-axis offset to the gyro_y_cal variable
    gyro_z_cal += gyro_z;                                              //Add the gyro z-axis offset to the gyro_z_cal variable
    delay(3);                                                          //Delay 3us to simulate the 250Hz program loop
  }
  gyro_x_cal /= 2000;                                                  //Divide the gyro_x_cal variable by 2000 to get the average offset
  gyro_y_cal /= 2000;                                                  //Divide the gyro_y_cal variable by 2000 to get the average offset
  gyro_z_cal /= 2000;                                                  //Divide the gyro_z_cal variable by 2000 to get the average offset

  oled.clear(PAGE);
  printTitle("Done", 0);
  Serial.println("CALIBRATION DONE$");
  write_SERIAL_CAL();
  delay(1000);
  oled.clear(PAGE);
  oled.display(); 
}


void check_MPU(){
  if ( (msecs - mpuMsecs >= (1000/mpu_sampling)) and (mpu_Enable)){
//    Serial.println((String)"$" + msecs);                          //DEBUG: Used to check process' period
    mpuMsecs = msecs;
    read_mpu_6050_data();
    write_SERIAL_MPU();
    ref_mpu_msecs += (1000/mpu_sampling);
//    Serial.println((String)"$" + msecs);                          //DEBUG: Used to check process' period
  }
}


void read_mpu_6050_data(){                                             //Subroutine for reading the raw gyro and accelerometer data
  Wire.beginTransmission(0x68);                                        //Start communicating with the MPU-6050
  Wire.write(0x3B);                                                    //Send the requested starting register
  Wire.endTransmission();                                              //End the transmission
  Wire.requestFrom(0x68,14);                                           //Request 14 bytes from the MPU-6050
  while(Wire.available() < 14);                                        //Wait until all the bytes are received
  acc_x = Wire.read()<<8|Wire.read();                                  //Add the low and high byte to the acc_x variable
  acc_y = Wire.read()<<8|Wire.read();                                  //Add the low and high byte to the acc_y variable
  acc_z = Wire.read()<<8|Wire.read();                                  //Add the low and high byte to the acc_z variable
  temp_mpu = Wire.read()<<8|Wire.read();                               //Add the low and high byte to the temperature variable
  gyro_x = Wire.read()<<8|Wire.read();                                 //Add the low and high byte to the raw_gyro_x variable
  gyro_y= Wire.read()<<8|Wire.read();                                  //Add the low and high byte to the raw_gyro_yvariable
  gyro_z= Wire.read()<<8|Wire.read();                                  //Add the low and high byte to the raw_gyro_zvariable

}


                                  // INTERRUPT ROUTINES


void isr1()
{
  cnta++;
}


void Timer2init() {

    // Setup Timer2 overflow to fire every 8ms (125Hz)
    //   period [sec] = (1 / f_clock [sec]) * prescale * (255-count)
    //                  (1/8000000)  * 64 * (255-130) = .008 sec

    TCCR2B = 0x00;                                                      // Disable Timer2 while we set it up

    TCNT2  = 130;                                                       // Reset Timer Count  (255-130) = execute ev 125-th T/C clock
    TIFR2  = 0x00;                                                      // Timer2 INT Flag Reg: Clear Timer Overflow Flag
    TIMSK2 = 0x01;                                                      // Timer2 INT Reg: Timer2 Overflow Interrupt Enable
    TCCR2A = 0x00;                                                      // Timer2 Control Reg A: Wave Gen Mode normal
    TCCR2B = 0x05;                                                      // Timer2 Control Reg B: Timer Prescaler set to 1024
}

ISR(TIMER2_OVF_vect) {

  ++msecs;                                                            // & count uSec every other time.
  TCNT2 = 256-125;                                                      // reset counter every 125th time (125*4us = 1ms)
  TIFR2 = 0x00;                                                         // clear timer overflow flag
};








                                  // DISPLAY FUNCTIONS
void oledSetup(){
  oled.begin();                                                        // Initialize the OLED
  oled.clear(ALL);                                                     // Clear the display's internal memory
  oled.display();
  delay(1000);
  oled.clear(PAGE);                                                   // Clear the buffer.
  oled.setCursor(0, 0);                                               // Set cursor to top-left
  oled.setFontType(0);                                                // Smallest font
  oled.print("SMART");
  oled.setCursor(0, 16);                                              // Set cursor to top-middle-left
  oled.print("CLAMP");
  oled.setCursor(0, 32);
  oled.print((String)"V."+ SMARTCLAMP_VERSION);
  oled.display();
  delay(2000);                                                        // Delay so user may see start screen
  oled.clear(PAGE);                                                   // Clear the buffer.
}

void registers_Error(){
  oled.clear(PAGE);                                                   // Clear the buffer.
  oled.setCursor(0, 0);                                               // Set cursor to top-left
  oled.setFontType(0);                                                // Smallest font
  oled.print("MPU REG");
  oled.setCursor(0, 16);                                              // Set cursor to top-middle-left
  oled.print("ERROR");
  oled.setCursor(0, 32);
  oled.print("RESET");
  oled.display();
}

void printTitle(String title, int font)
{
  oled.clear(PAGE);
  int middleX = oled.getLCDWidth() / 2;
  int middleY = oled.getLCDHeight() / 2;

  oled.clear(PAGE);
  oled.setFontType(font);
  // Try to set the cursor in the middle of the screen
  oled.setCursor(middleX - (oled.getFontWidth() * (title.length() / 2)),
                 middleY - (oled.getFontHeight() / 2));
  // Print the title:
  oled.print(title);
  oled.display();
}

void oledProcess1(){
  oled.clear(PAGE);                                                   // Clear the display
  oled.setCursor(0, 0);                                               // Set cursor to top-left
  oled.setFontType(0);                                                // Smallest font
  oled.print("T:");                                                   // Print "T"
}

void oledProcess2(){
  if (hours > 0){
    oled.print((String)hours + ":");  
  }
  if (secs >= 10){
    oled.print((String)mins+":"+secs);                                
  }else{
    oled.print((String)mins+":0"+secs); 
  }
}

void oledProcess3(){
  oled.setCursor(0, 16);                                               // Set cursor to top-middle-left
  oled.print("I:");
  oled.print(Ia);
  }

void oledProcess4(){
  oled.setCursor(0, 32);
  oled.print("LED: "); 
  oled.setFontType(1);
  if (lightOn){
    oled.print("ON");
  }else{
    oled.print("OFF");
  }
}

void oledProcess5(){
  oled.display();
  }




  
                                  // OTHER FUNCTIONS

void processTime(){
  secs++;
  if (secs >= 60){
  mins++;
  secs = 0;
  if (mins >= 60){
    mins = 0;
    hours++;
    }
  }
}

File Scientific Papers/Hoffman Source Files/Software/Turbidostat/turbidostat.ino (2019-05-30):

/*
 *    FILE: turbidostat.ino
 *  AUTHOR: Christian Wohltat, Stefan Hoffman
 *    DATE: 2016 05 09
 *
 *  PURPOSE:
 */
#define TURBIDOSTAT_VERSION  "0.2"
#define NO_PORTB_PINCHANGES // to indicate that port b will not be used for pin change interrupts
#define NO_PORTC_PINCHANGES // to indicate that port c will not be used for pin change interrupts

#define PINMODE
#define FLASH
#include <PinChangeInt.h>
#include <EEPROM.h>
#include <avr/eeprom.h>

#define SENSOR_A_PIN  2
#define SENSOR_B_PIN  3
#define HALLPIN       4
#define PUMPPIN       5
#define STIRRERPIN    6
#define AIRPUMPPIN    10

#define EEPROM_OFFSET 0
#define EEPROM_TARGET_I                (0*sizeof(unsigned long))
#define EEPROM_I_0                     (1*sizeof(unsigned long))
#define EEPROM_PUMP_MODE               (2*sizeof(unsigned long))
#define EEPROM_PUMP_POWER              (3*sizeof(unsigned long))
#define EEPROM_AIRPUMP_POWER           (4*sizeof(unsigned long))
#define EEPROM_PUMP_PULS_DURATION      (5*sizeof(unsigned long))
#define EEPROM_PUMP_PULS_WAIT          (6*sizeof(unsigned long))
#define EEPROM_STIRRER_RPM             (7*sizeof(unsigned long))

volatile unsigned long cnta = 0;
volatile unsigned long cntb = 0;
volatile unsigned long stirrerIntCnt = 0;
unsigned long oldcnta = 0;
unsigned long oldcntb = 0;
unsigned long t = 0;

#define SERIAL_BUFFER_LEN 128
char serialBuffer[SERIAL_BUFFER_LEN];
unsigned short bufferEnd = 0;
unsigned short bufferPos = 0;

// stirrer parameter
byte stirrerOut = 30;
unsigned long stirrerRPM = 800;  // in Hz

// OD measurement parameter
float targetOD = 1;
float OD = 0;
unsigned long Ia = 0;         // current intensity of sensor A in uW/m2
unsigned long Ib = 0;         // current intensity of sensor B in uW/m2
unsigned long I = 0;         // current intensity in uW/m2
unsigned long targetI = 0;   // target intensity in uW/m2
unsigned long I_0 = 0;       // zero intensity in uW/m2

// pump parameter
unsigned long pumpMode = 0;
unsigned long pumpPower = 255;
unsigned long airpumpPower = 0;
unsigned long pumpPulsDuration = 100;  // in ms
unsigned long pumpPulsWait = 5000;     // in ms
byte thresholdCnt = 0;
#define NTIMESTHRESHOLD  3


//////////////////////////////
//
// PROTOTYPES
//
//////////////////////////////
void            processSerialBuffer();
unsigned long   getSerialIntArgument();
void            setPwmFrequency(int pin, int divisor);
double          getArduinoTemp(void);
void            setupADC();


// INTERRUPT ROUTINES
void irq1()
{
  cnta++;
}

void irq2()
{
  cntb++;
}

void irq3()
{
  stirrerIntCnt++;
}

/*
 * From sample interrupt code published by Noah Stahl on his blog, at:
 * http://arduinomega.blogspot.com/p/arduino-code.html
 *
 */


/*** FUNC

Name:           Timer2init

Function:       Init timer 2 to interrupt periodically. Call this from
                the Arduino setup() function.

Description:    The pre-scaler and the timer count divide the timer-counter
                clock frequency to give a timer overflow interrupt rate:

                Interrupt rate =  16MHz / (prescaler * (255 - TCNT2))

        TCCR2B[b2:0]   Prescaler    Freq [KHz], Period [usec] after prescale
          0x0            (TC stopped)     0         0
          0x1                1        16000.        0.0625
          0x2                8         2000.        0.500
          0x3               32          500.        2.000
          0x4               64          250.        4.000
          0x5              128          125.        8.000
          0x6              256           62.5      16.000
          0x7             1024           15.625    64.000


Parameters: void

Returns:    void

FUNC ***/

void Timer2init() {

    // Setup Timer2 overflow to fire every 8ms (125Hz)
    //   period [sec] = (1 / f_clock [sec]) * prescale * (255-count)
    //                  (1/16000000)  * 1024 * (255-130) = .008 sec

    TCCR2B = 0x00;        // Disable Timer2 while we set it up

    TCNT2  = 130;         // Reset Timer Count  (255-130) = execute ev 125-th T/C clock
    TIFR2  = 0x00;        // Timer2 INT Flag Reg: Clear Timer Overflow Flag
    TIMSK2 = 0x01;        // Timer2 INT Reg: Timer2 Overflow Interrupt Enable
    TCCR2A = 0x00;        // Timer2 Control Reg A: Wave Gen Mode normal
    TCCR2B = 0x05;        // Timer2 Control Reg B: Timer Prescaler set to 1024
}


extern volatile unsigned long msecs = 0;


/*** FUNC
Name:       Timer2 ISR
Function:   Handles the Timer2-overflow interrupt
Description:
Parameters: void
Returns:    void
FUNC ***/

ISR(TIMER2_OVF_vect) {
  static unsigned char count;            // interrupt counter

  //if( (++count & 0x01) == 0 )     // bump the interrupt counter
    ++msecs;              // & count uSec every other time.
  TCNT2 = 256-125;                // reset counter every 125th time (125*4us = 1ms)
  TIFR2 = 0x00;                   // clear timer overflow flag
};


void eeprom_save(){
  eeprom_write_block((const void*)&targetI,           (void*)EEPROM_TARGET_I + EEPROM_OFFSET,           sizeof(unsigned long));
  eeprom_write_block((const void*)&I_0,               (void*)EEPROM_I_0 + EEPROM_OFFSET,                sizeof(unsigned long));
  eeprom_write_block((const void*)&stirrerRPM,        (void*)EEPROM_STIRRER_RPM + EEPROM_OFFSET,        sizeof(unsigned long));
  eeprom_write_block((const void*)&pumpPulsDuration,  (void*)EEPROM_PUMP_PULS_DURATION + EEPROM_OFFSET, sizeof(unsigned long));
  eeprom_write_block((const void*)&pumpPulsWait,      (void*)EEPROM_PUMP_PULS_WAIT + EEPROM_OFFSET,     sizeof(unsigned long));
  eeprom_write_block((const void*)&pumpMode,          (void*)EEPROM_PUMP_MODE + EEPROM_OFFSET,          sizeof(unsigned long));
  eeprom_write_block((const void*)&pumpPower,         (void*)EEPROM_PUMP_POWER + EEPROM_OFFSET,         sizeof(unsigned long));
  eeprom_write_block((const void*)&airpumpPower,      (void*)EEPROM_AIRPUMP_POWER + EEPROM_OFFSET,      sizeof(unsigned long));
}
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

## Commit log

2019-04-30 Added Annotated scientific Papers and All files needed to create the Hoffman turbidostat
    [base plate.stl, bottom cover.stl, lower housing.stl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]
2019-04-30 Addeed the Materials Inventory Spreadsheet with all the materials needed to build Hoffman's turbidostat
    [Materials Inventory.xlsx]
2019-05-30 Adde Spec Sheets of Current Components
2019-06-01 Smartclamp 0.01: Basic functionality to read data from light sensor, turn on and off the laser, communicate with PC through serial and interpret commands
2019-06-04 Added Python code to find arduino's USB serial, connect, read and interpret its data and log in CSV and TXT file. Still missing serial input functionality and proper serial closing
    [2019-06-04_15-01-51.csv]
2019-06-10 Working Python interface able to send and receive messages through usb serial (Windows not tested yet), Saves data into CSV and TXT logs.
    [2019-06-04_15-01-51.csv]
2019-06-11 Added Arduino code to read en send data from gyroscope MPU-6050 [in Sample Code]. Did test on Gyro's raw data to check if it was usable [Tests Folder]. Moved all 3rd Party Code snippets to its own fo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
    [Rotation tests.xlsx]
2019-06-13 Added new data sheets and reorganized the folder. Started implementation of gyroscope in smartclapEXP.py (still highly unstable).
    [Materials Inventory.xlsx]
2019-06-19 smartclamp.ino now fully interfaces with gyroscope and light sensor. LED's brightness is controlled by a digital potentiometer. Converts raw values to standard units. All outputs end in $ to aid seri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
    [Apple Juice OD.xlsx]
2019-06-23 Added Automatic Brightness Test to smartclampEXP.py. Modified smartclamp.ino to start with LED off and signal when calibration is done. Stored Graphs from tests under Test folder. Updated data sheets.
    [2019-06-20_11-50-12.csv, 2019-06-20_14-56-50.csv, LED_no_filter.csv]
2019-06-30 Added Automatic Testing Capabilities to Python. smartclamp.ino now refers to 5V Arduino Nano implementation. smartclamp3v3.ino is the 3v3 Arduino Pro Mini implementation with display capabilities. Ra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
    [0%AJ1.csv, 0%AJ2.csv, 10%AJ1.csv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]
2019-07-03 Stablized and added functionality to SmartClamp3V3.ino . Added commands to Set MPU Sampling (SMS #), Display On (DON), and Display Off (DOF). Arduino main loop was optimized and can achieve 100 Hz MP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
    [2019-07-02_16-28-12.csv, 2019-07-02_16-56-33.csv, 2019-07-02_16-58-41.csv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]
2019-07-03 Minor fix to ensure seconds time is printed before 0 ms gyro datapoint. Confirmed Max MPU Sampling freq is 111 Hz (unstable since not a factor of 1000)
    [SmartClamp3v3.ino]
2019-07-10 Updated smartclamp5V.ino and smartclampEXP.py to support 100 Hz sampling rate for MPU and Light detection.
    [2019-07-02_16-28-12.csv, 2019-07-02_16-56-33.csv, 2019-07-02_16-58-41.csv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]
2019-09-08 Reorganized Github folder for greater clarity. Details of each test may now be found on the details of the folders containing them. Updated smartclamp.py to version 0.13.
    [0%AJ1.csv, 0%AJ2.csv, 10%AJ1.csv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]
2019-09-08 Migrated smartclamp.ino v.0.13 from Arduino Nano board to smartclamp.cpp v0.14 for ESP32 board. MPU and OLED display functionality had been disabled as they are non-essential for near-future tests. P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
    [smartclamp.cpp]
2019-09-08 added circuit schematic
    [2019-09-08_20-09-00.csv, smartclamp v0.14.sch]
